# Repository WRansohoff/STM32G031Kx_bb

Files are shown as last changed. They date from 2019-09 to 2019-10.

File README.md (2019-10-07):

# Simple STM32G031Kx Breakout Board

This is just a simple reference circuit for a 32-pin STM32G031 microcontroller. I tried to make it easy to hand-solder, with everything on one side of the board, wide footprints, and no parts smaller than 0805. The microcontroller also has pins spaced at 0.8mm, which is farther apart than the usual <=0.5mm that you see these days. Some of the parts are a little close together, so you might have to think about the order that you solder them on if you don't reflow it. But it should be do-able without much soldering experience required.

Note: Embarrassingly, I forgot to connect the +3.3V line to the microcontroller's `VDD` pin on the first revision, so the boards only worked after I soldered a wire between those two nets. That should be fixed now, but I can't guarantee that until I've ordered and tested the new revision. I'm also thinking of replacing the through-hole crystal with a surface-mount one, so the BoM might still change slightly.

Sorry for the inconvenience, in the meantime!

# Board Renders:

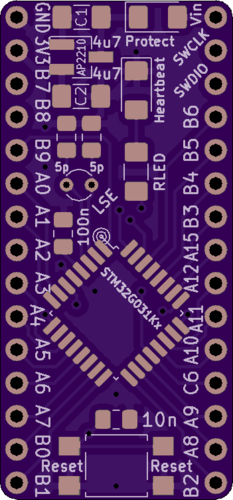
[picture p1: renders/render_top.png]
Board Top

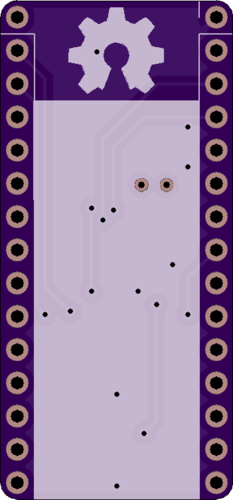
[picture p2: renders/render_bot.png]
Board Bottom


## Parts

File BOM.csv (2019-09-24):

Part ID | Part type | Part size | Part value | Example Digikey Item | Cost (qty: 1) | Comment
C1, C2 | Capacitor | 1206 | 4.7μF | https://www.digikey.com/short/p2pnd5 | $0.50 | Bulk power supply decoupling capacitors. 2.2μF - 10μF is probably fine, prefer X5/X7 ceramic capacitors with low ESR.
C2, C3 | Capacitor | 0805 | 5pF | https://www.digikey.com/short/p2pnrf | $0.20 | Filtering capacitors for the 32.768KHz low-speed crystal oscillator. The actual value depends on your crystal, but it will probably be between 0-15pF and isn't hugely important. Prefer C0G/NP0 ceramic capacitors.
C5 | Capacitor | 0805 | 100nF | https://www.digikey.com/short/p2pnw5 | $0.10 | Decoupling capacitor for the only power pair of supply pins on the QFP32 STM32G031 package. Prefer X5/X7 ceramic capacitors.
C6 | Capacitor | 0805 | 10nF | https://www.digikey.com/short/p2pn24 | $0.10 | Filtering capacitor for the reset button. This is recommended by ST's application notes. Although, I wonder - should there also be a resistor in series between the reset pin and the button?
D1 | Schottky Diode | 1206 | 20-40V, 0.5-2A | https://www.digikey.com/short/p2pnv4 | $0.40 | Schottky diode to protect against reverse polarity. This will probably introduce a ~0.3-0.6V drop before the voltage regulator, but it should prevent the circuit from frying if you swap + and - by accident.
D2 | LED | 1206 | Your favorite color | https://www.digikey.com/short/p2pdmb | $0.20 | Heartbeat' LED - it's nice for a board to include at least one LED for a program to use. Also, the QFP32 STM32G031 includes a single pin from the GPIOC bank, which is nice for this sort of thing. I think that you aren't supposed to sink more than 20mA from each bank, so using pin C6 to drive an LED doesn't limit what we can do on the GPIOA or GPIOB banks.
J1, J2 | Pin Header or Socket Row | 0.1" | 1x15 | https://www.digikey.com/short/p2pdvt | $0.74 | These are generic parts, and you can find them much more cheaply on eBay, Amazon, AliExpress, etc. You can usually get good deals on bunches of 1x40 rows, and cut them to size.
R1 | Resistor | 1206 | 1KΩ | https://www.digikey.com/short/p2p0ht | $0.10 | If you want to use PWM to drive the LED, maybe 220-470Ω would be better. If you want it to be dim, maybe 4.7KΩ-10KΩ? Red/yellow LEDs will be brighter than green/blue/white LEDs for the same value of resistance, because their forward voltages are lower.
SW1 | Button | 0.45"x0.45" | SPST | https://www.digikey.com/short/p2p09q | $0.22 | I picked the 'TL3305A' part because it was reasonably cheap and in the default KiCAD footprint library. But any old 4-leg SMD 0.45"x0.45" tactile button will probably work.
U1 | Microcontroller | LQFP-32 | STM32G031Kx | https://www.digikey.com/short/p2p05b | $1.86 | The core MCU. Be sure to double-check where pin #1 goes - look in the datasheet for the 'pin 1' marking location. There are currently two versions available; the one ending in 'K6' is cheaper, but only has 32KB of Flash memory. The one ending in 'K8' has 64KB Flash.
U2 | Voltage Regulator | SOT-23 | AP2210-3.3 | https://www.digikey.com/short/p2p090 | $0.42 | I like this voltage regulator because it only has 3 pins, it can supply a decent 300mA, and it works with up to a 13V input. But I'm starting to think it's a good idea to use regulators with 'power good' pins tied to the reset line.
Y1 | Crystal | 2mm-Diameter | 32.768KHz | https://www.digikey.com/short/p2p0b2 | $0.21 | Low-Speed External' crystal oscillator. I used a cylindrical 2mm-diameter through-hole crystal because it's a very standard size, but here's an exercise for the reader - replace it with a small SMD crystal!
Total | - | - | - | - | $5.05 | You can pay a bit less per unit if you buy in 10s or 100s, but then you'd need to make 10 or 100 of these. SMD resistors and capacitors can be worth buying in bulk, though.

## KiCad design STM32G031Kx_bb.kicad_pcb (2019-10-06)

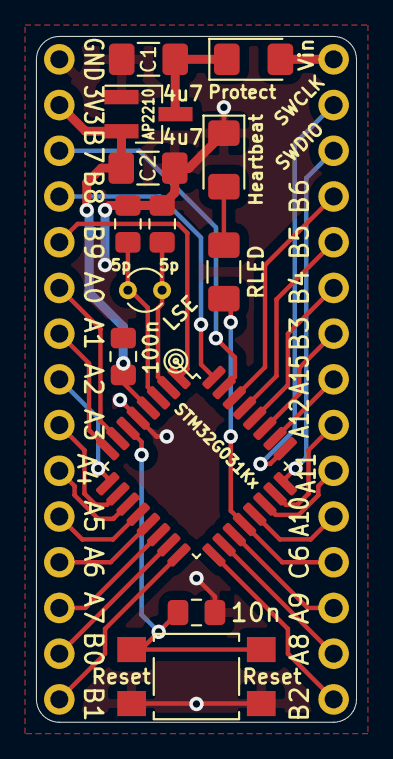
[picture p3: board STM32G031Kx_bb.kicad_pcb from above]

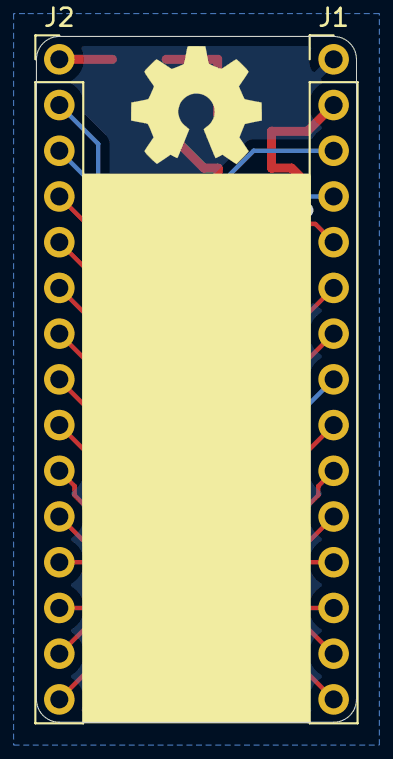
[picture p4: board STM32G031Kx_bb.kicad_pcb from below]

Board: 2 copper layers, 17.8 x 38.1 mm, 15 parts (2 on the bottom side), 35 nets.

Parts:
C1, C2: 4u7; C_1206_3216Metric_Pad1.42x1.75mm_HandSolder
C3, C4: 5p; C_0805_2012Metric_Pad1.15x1.40mm_HandSolder
C5: 100n; C_0805_2012Metric_Pad1.15x1.40mm_HandSolder
C6: 10n; C_0805_2012Metric_Pad1.15x1.40mm_HandSolder
D1: Protect; D_1206_3216Metric_Pad1.42x1.75mm_HandSolder
D2: Heartbeat; LED_1206_3216Metric_Pad1.42x1.75mm_HandSolder
J1: GPIO1; PinHeader_1x15_P2.54mm_Vertical
J2: GPIO2; PinHeader_1x15_P2.54mm_Vertical
R1: RLED; R_1206_3216Metric_Pad1.42x1.75mm_HandSolder
SW1: Reset; SW_SPST_TL3305A
U1: STM32G031Kx; LQFP-32_7x7mm_P0.8mm
U2: AP2210; SOT-23_Handsoldering
Y1: LSE; Crystal_Round_D2.0mm_Vertical

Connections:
A0: J1.6, U1.7
A1: J1.7, U1.8
A2: J1.8, U1.9
A3: J1.9, U1.10
A4: J1.10, U1.11
A5: J1.11, U1.12
A6: J1.12, U1.13
A7: J1.13, U1.14
A8: J2.14, U1.18
A9: J2.13, U1.19
A10: J2.11, U1.21
A11: J2.10, U1.22
A12: J2.9, U1.23
A15: J2.8, U1.26
B0: J1.14, U1.15
B1: J1.15, U1.16
B2: J2.15, U1.17
B3: J2.7, U1.27
B4: J2.6, U1.28
B5: J2.5, U1.29
B6: J2.4, U1.30
B7: J1.3, U1.31
B8: J1.4, U1.32
B9: J1.5, U1.1
C6: J2.12, R1.1, U1.20
GND: C1.2, C2.2, C3.2, C4.1, C5.2, C6.2, D2.1, J1.1, SW1.1, U1.5, U2.1
unnamed: C1.1, D1.1, U2.3
unnamed: C3.1, U1.3, Y1.1
unnamed: C4.2, U1.2, Y1.2
unnamed: C6.1, SW1.2, U1.6
unnamed: D2.2, R1.2
SWCLK: J2.2, U1.25
SWDIO: J2.3, U1.24
VDD: C2.1, C5.1, J1.2, U1.4, U2.2
VPP: D1.2, J2.1

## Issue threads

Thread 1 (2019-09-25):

Some feedback

deltabeard, 2019-09-25:
Hi, great work on the PCB. I have some suggestions after a brief look in KiCAD.

- Reset is written twice next to switch SW1. I would delete the "PCB Text" label.
- Some components are referred to by their reference, but some by their function. Like D2 is labelled as "Heartbeat", but C1, C2 aren't. I personally prefer just using the reference name placed under where the component is going to sit, and also the function text placed visibly next to the component. So SW1 would be under the switch when it's soldered so you wouldn't see it, but "Reset" would be next to it and visible.
- Regarding LSE, I would specify on the schematic that this is a 32.768KHz oscillator, since the STM32G031K6 has an internal "32KHz" oscillator already.
- I would have the oscillator mounted on the PCB horizontally instead of vertically as to avoid accidentally hitting it.
- Regarding R1, the value should be the resistance instead of text "RLED". So something like 330R for example.
- I can't tell if the VDD pin of the microcontroller is connected to the VDD pin of the voltage regulator.
- The schematic could be made simpler by using separate ground ports for the different functions. So the reset button should have it's own ground port instead of connecting it all the way to the power supply ground port. Same with VDD decoupling capacitor C5 and the OSC caps C3 and C4 too.
- The AP2210 datasheet lists "Reverse-battery Protection" as a feature, but doesn't really elaborate. I wonder therefore if the protection diode is required? Maybe something to test when you get your PCB.
- The AP2210 datasheet uses a 1uF and 2.2uF input and output capacitors respectively in the typical applications circuit. Maybe you could reduce the 4.7uF you've selected to 2.2uF to reduce the size (and cost?) of the caps you're using.

Finally, I wonder if it's possible to have most of these components on the bottom side of the PCB? The breadboard connectors typically have (I think) about 1 or 2mm of clearance, so some components like the microcontroller, capacitors and resistors could go under. That way, the text of the breadboard connectors could be made straight and larger. Also, you'd be able to space the components out a bit more making it easier to solder, etc.

I think I tried this myself when making a minimal PIC16F1516 breakout two years ago. It just had a decoupling capacitor and a breadboard connector! 😂

WRansohoff, 2019-10-25:
Hi, thank you for the feedback! You're right that the microcontroller's V++ pin wasn't connected to the voltage regulator output -  whoops! I've fixed that, but I'm still waiting on the second revision of boards. The first ones did work after I soldered a wire between the regulator and the MCU's decoupling capacitor, but jeez - I must have drawn that circuit a dozen times, I guess that's complacency for you :)

Good points about the LSE oscillator, I'm thinking of replacing it with a 3.2x1.5mm surface-mount crystal to make it a real single-sided board. I'm not sure why I thought the cylinder was a more standard part size, honestly...

And you're right that I should also standardize which silkscreen markings I render. It isn't really consistent, and it wouldn't make much sense for automated assembly, I just like being able to see which values go where without needing to look at the schematic for every single footprint. I guess it's one of those bad habits that go against conventional design, like how I draw the microcontroller's schematic symbol as a square with clockwise-numbered pins instead of grouping the pins by function.

Good points about using smaller capacitors with the voltage regulator and omitting the reverse-polarity diode, too; I do usually overrate the power supply decoupling capacitors a little bit, and I include a schottky diode in most of my microcontroller boards out of habit more than anything else.

It would be possible to have some components on the rear to save a bit of space, but it's a simple design and single-sided assembly is easier to deal with since you don't have to deal with uneven bottom surfaces.

Anyways, thanks for the feedback! You might like the new 8-pin STM32 microcontroller: they can work with only a single 100nF decoupling capacitor between two adjacent pins.

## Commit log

2019-09-24 Add readme and bill of materials
    [BOM.csv]
2019-09-24 Add core project files, and custom parts library.
    [STM32G031Kx_bb.kicad_pcb, STM32G031Kx_bb.sch]
2019-09-24 Add a couple more files.
2019-09-24 Remove the netlist; it's one button-click away, and I don't think that counts as a 'core file'.
2019-09-24 Add OSHPark renders of the board top/bottom
2019-09-24 Clean up the silkscreen markings a bit.
    [STM32G031Kx_bb.kicad_pcb]
2019-10-06 Connect the MCU power supply to the voltage regulator's output...whoops!
    [STM32G031Kx_bb.kicad_pcb, STM32G031Kx_bb.sch]
